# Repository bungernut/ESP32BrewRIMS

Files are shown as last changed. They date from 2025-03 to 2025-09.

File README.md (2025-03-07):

# ESP32BrewREMS

# Documentation
I dont know why, but it's been a real pain to find documentation for the ESP32 device. I'm using a HiLetgo ESP32 OLED WiFi Kit V3. This is apparently really a product by Heltec: https://heltec.org/project/wifi-kit32-v3/

USB-Serial Driver: https://www.silabs.com/developer-tools/usb-to-uart-bridge-vcp-drivers

This library seems to be really important https://github.com/HelTecAutomation/Heltec_ESP32

None of their links work, so I'm going to try to scrape together what I can find:  
## Specifications
* Master Chip  ESP32-S3FN8(Xtensa®32-bit lx7 dual core processor)  
* USB to Serial Chip  CP2102  
* WiFi  802.11 b/g/n, up to 150Mbps  
* Bluetooth LE  Bluetooth 5, Bluetooth mesh  
* Hardware Resource  7*ADC1+2*ADC2; 7*Touch; 3*UART; 2*I2C; 2*SPI, etc.  
* Memory  384KB ROM;  512KB SRAM;  16KB RTC SRAM;  8MB SiP Flash  
* 2*1.25 lithium battery interface;  2*18*2.54 Header Pin  
* Battery  3.7V lithium battery power supply and charging  



### Encoder Input
I should have looked at the spec sheet. I think the circuit is close w/ the input pullup:
https://www.digikey.com/en/products/detail/bourns-inc/PEC11H-4220F-S0024/12349532


ledc is a little weird but we're trying to use if for power control (https://docs.espressif.com/projects/arduino-esp32/en/latest/api/ledc.html).
The range of settings is limited between freq and resolution.
Run this script to get the output https://github.com/espressif/arduino-esp32/blob/master/libraries/ESP32/examples/AnalogOut/ledcFrequency/ledcFrequency.ino
```
Bit resolution | Min Frequency [Hz] | Max Frequency [Hz]
             1 |              19532 |           20039138
             2 |               9766 |           10019569
             3 |               4883 |            5009784
             4 |               2442 |            2504892
             5 |               1221 |            1252446
             6 |                611 |             626223
             7 |                306 |             313111
             8 |                153 |             156555
             9 |                 77 |              78277
            10 |                 39 |              39138
            11 |                 20 |              19569
            12 |                 10 |               9784
            13 |                  5 |               4892
            14 |                  3 |               2446
```

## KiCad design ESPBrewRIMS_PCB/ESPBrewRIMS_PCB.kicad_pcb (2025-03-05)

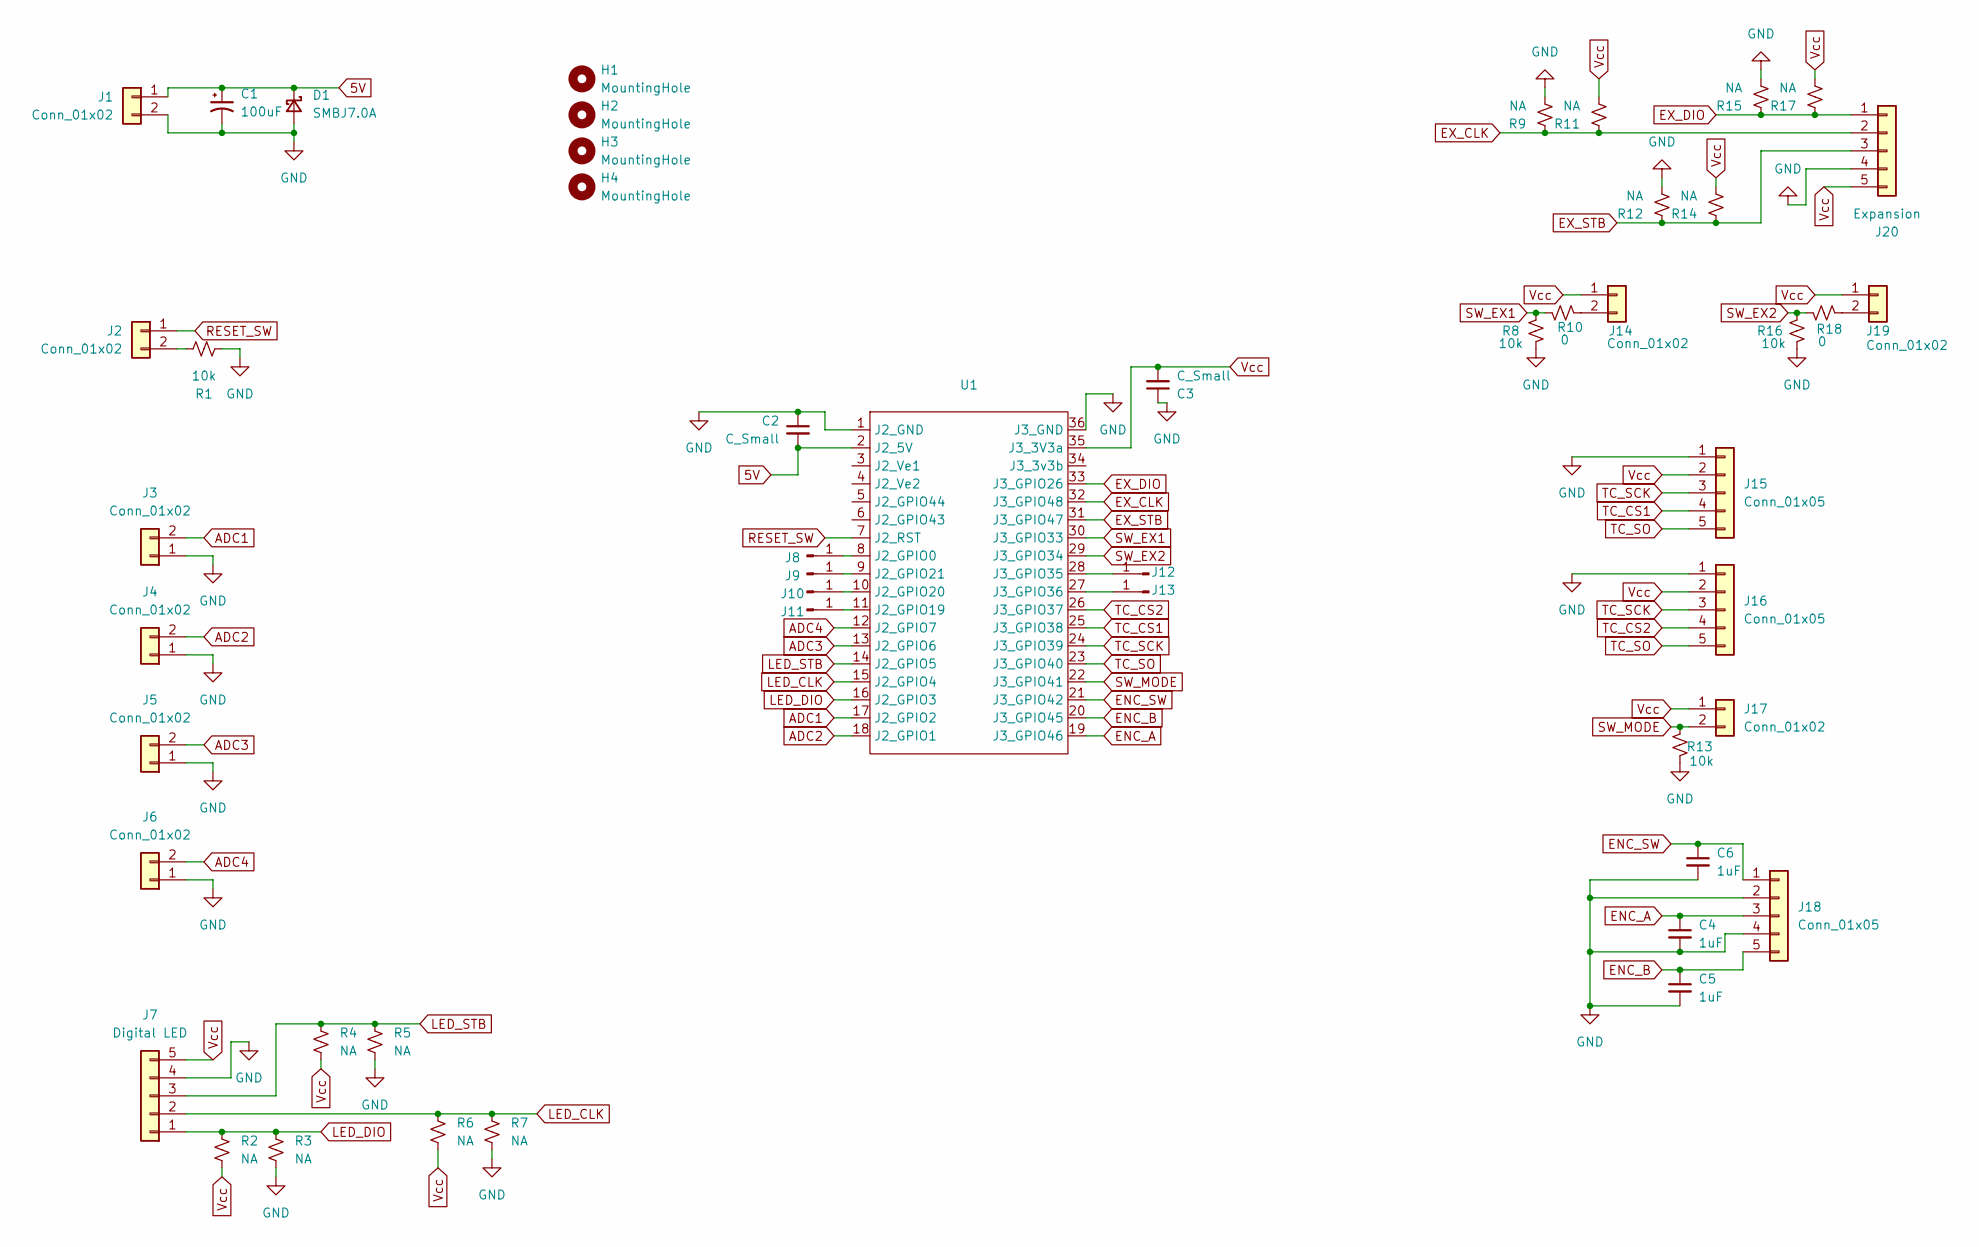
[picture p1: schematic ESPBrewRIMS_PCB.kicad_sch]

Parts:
C1: 100uF; CP_Radial_D8.0mm_P3.50mm
C2, C3: C_Small; C_0805_2012Metric_Pad1.18x1.45mm_HandSolder
C4, C5, C6: 1uF; C_0805_2012Metric_Pad1.18x1.45mm_HandSolder
D1: SMBJ7.0A; D_SMA-SMB_Universal_Handsoldering
H1, H2, H3, H4: MountingHole; MountingHole_3mm
J1, J2, J3, J4, J5, J6, J14, J17, J19: Conn_01x02; Molex_SL_171971-0002_1x02_P2.54mm_Vertical
J7: Digital LED; Molex_SL_171971-0005_1x05_P2.54mm_Vertical
J8, J9, J10, J11, J12, J13: Conn_01x01_Pin; PinSocket_1x01_P2.54mm_Vertical
J15, J16, J18: Conn_01x05; Molex_SL_171971-0005_1x05_P2.54mm_Vertical
J20: Expansion; PinHeader_1x05_P2.54mm_Vertical
R1, R8, R13, R16: 10k; R_0805_2012Metric_Pad1.20x1.40mm_HandSolder
R2, R3, R4, R5, R6, R7, R9, R11, R12, R14, R15, R17: NA; R_0805_2012Metric_Pad1.20x1.40mm_HandSolder
R10, R18: 0; R_0805_2012Metric_Pad1.20x1.40mm_HandSolder
U1: DIP-36_907_ELL

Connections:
5V: C1.1, C2.2, D1.1 (K), J1.1, U1.2 (J2_5V)
ADC1: J3.2, U1.17 (J2_GPIO2)
ADC2: J4.2, U1.18 (J2_GPIO1)
ADC3: J5.2, U1.13 (J2_GPIO6)
ADC4: J6.2, U1.12 (J2_GPIO7)
ENC_A: C4.1, J18.3, U1.19 (J3_GPIO46)
ENC_B: C5.1, J18.5, U1.20 (J3_GPIO45)
ENC_SW: C6.1, J18.1, U1.21 (J3_GPIO42)
EX_CLK: J20.2, R9.1, R11.1, U1.32 (J3_GPIO48)
EX_DIO: J20.1, R15.1, R17.1, U1.33 (J3_GPIO26)
EX_STB: J20.3, R12.1, R14.1, U1.31 (J3_GPIO47)
GND: C1.2, C2.1, C3.1, C4.2, C5.2, C6.2, D1.2 (A), J1.2, J3.1, J4.1, J5.1, J6.1, J7.4, J15.1, J16.1, J18.2, J18.4, J20.4, R1.2, R3.2, R5.2, R7.2, R8.2, R9.2, R12.2, R13.2, R15.2, R16.2, U1.1 (J2_GND), U1.36 (J3_GND)
LED_CLK: J7.2, R6.1, R7.1, U1.15 (J2_GPIO4)
LED_DIO: J7.1, R2.1, R3.1, U1.16 (J2_GPIO3)
LED_STB: J7.3, R4.1, R5.1, U1.14 (J2_GPIO5)
unnamed: J2.2, R1.1
unnamed: J8.1, U1.8 (J2_GPIO0)
unnamed: J9.1, U1.9 (J2_GPIO21)
unnamed: J10.1, U1.10 (J2_GPIO20)
unnamed: J11.1, U1.11 (J2_GPIO19)
unnamed: J12.1, U1.28 (J3_GPIO35)
unnamed: J13.1, U1.27 (J3_GPIO36)
unnamed: J14.2, R10.2
unnamed: J19.2, R18.2
RESET_SW: J2.1, U1.7 (J2_RST)
SW_EX1: R8.1, R10.1, U1.30 (J3_GPIO33)
SW_EX2: R16.1, R18.1, U1.29 (J3_GPIO34)
SW_MODE: J17.2, R13.1, U1.22 (J3_GPIO41)
TC_CS1: J15.4, U1.25 (J3_GPIO38)
TC_CS2: J16.4, U1.26 (J3_GPIO37)
TC_SCK: J15.3, J16.3, U1.24 (J3_GPIO39)
TC_SO: J15.5, J16.5, U1.23 (J3_GPIO40)
Vcc: C3.2, J7.5, J14.1, J15.2, J16.2, J17.1, J19.1, J20.5, R2.2, R4.2, R6.2, R11.2, R14.2, R17.2, U1.35 (J3_3V3a)

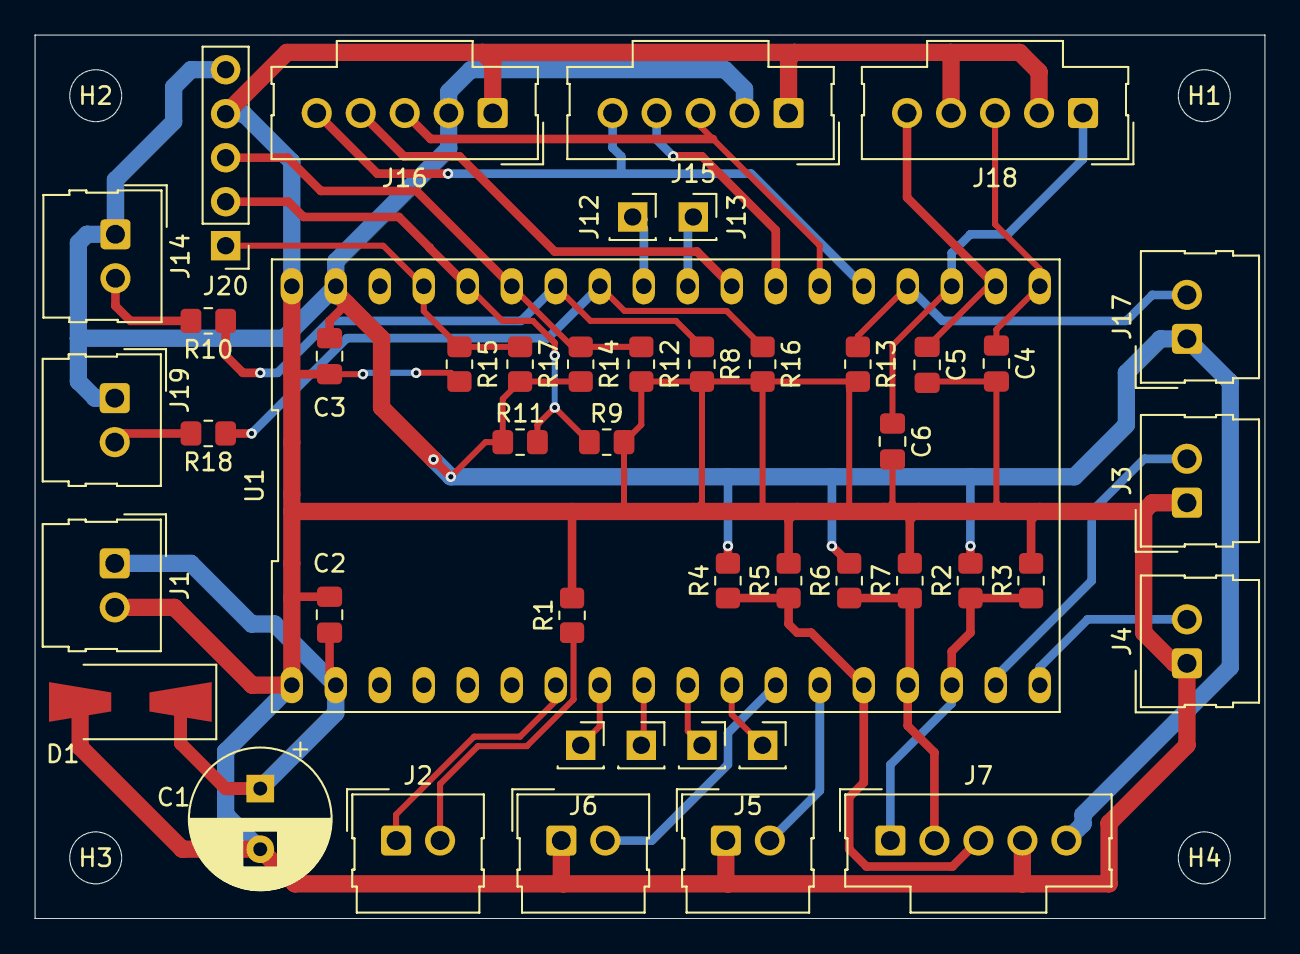
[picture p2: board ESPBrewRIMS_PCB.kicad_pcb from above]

Board: 2 copper layers, 71.0 x 51.0 mm, 50 parts (0 on the bottom side), 33 nets.

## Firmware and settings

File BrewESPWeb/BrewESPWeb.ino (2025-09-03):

#include "SECRETS.h"
#include <WiFi.h>
#include <WebServer.h>
#include <Wire.h>
#include <SPI.h>
#include "HT_SSD1306Wire.h"  // legacy include: `#include "SSD1306.h"`
#include "max6675.h"         // Adafruit Thermocouple
#include <AutoPID.h>         // https://ryand.io/AutoPID/#autopidautopid-constructor

/*
Heltec WiFi Kit 32(V3)

*/

const char* ssid = MY_SSID;
const char* password = MY_PASSKEY;

#define PINLED 35   // Onboard White LED
#define PINSSR 6    // Use this one for heater relay control
#define PIN_POW A1  // The ADC for the POWer

#define PIN_SCK 39    //TC1/2
#define PIN_SDO 40    //TC1/2
#define PIN_TC1CS 38  //TC1
#define PIN_TC2CS 37  //TC2

// Setup Hardware
WebServer server(80);
String header;
//WiFiClient wifi_client;
static SSD1306Wire display(0x3c, 500000, SDA_OLED, SCL_OLED, GEOMETRY_128_64, RST_OLED);  // addr , freq , i2c group , resolution , rst
MAX6675 thermocouple1(PIN_SCK, PIN_TC1CS, PIN_SDO);
MAX6675 thermocouple2(PIN_SCK, PIN_TC2CS, PIN_SDO);

// These are parameter that are set by users with whatever UI
double mashsettemp = 150;      // Set point for mash temperature in F
double maxrimstemp = 160;      // Max temp at output of the RIMS heater
bool enable_ops = false;  // A switch that disables the heater and stuff

double mashtemp = 0;
double rimstemp = 0;
double power_tot = 0;
double pid_out = 0;
const double KP = 10.;
const double KI = 0.1;  //.0003
const double KD = 0.1;  //.01;
const int OUTPUT_MIN = 0;
const int OUTPUT_MAX = 3276;  //maxheaterset / heaterspec * 4095.
AutoPID myPID(&rimstemp, &mashsettemp, &pid_out, OUTPUT_MIN, OUTPUT_MAX, KP, KI, KD);


// Function to handle the root URL and show the current states
void handleRoot() {
  String html = "<!DOCTYPE html><html><head><meta name=\"viewport\" content=\"width=device-width, initial-scale=1\">";
  html += "<link rel=\"icon\" href=\"data:,\">";
  html += "<style>html { font-family: Helvetica; display: inline-block; margin: 0px auto; text-align: center; font-size: 20px}";
  html += ".button { background-color: #4CAF50; border: none; color: white; padding: 12px 20px; \
                     border-radius: 8px; text-decoration: none; font-size: 20px; margin: 2px; cursor: pointer;}";
  html += ".button2 { background-color: #555555; }</style></head>";
  html += "<body><h1>ESPBrew</h1>";
  html += "<p>";
  if (enable_ops == false) {
    html += "<span style=\"color:red;\">DISABLED</span>&nbsp;";
    html += "<a href=\"/enable\"><button class=\"button\">ENABLE</button></a>";
  } else {
    html += "<span style=\"color:green;\">ENABLED</span>&nbsp;";
    html += "<a href=\"/disable\"><button class=\"button\", style=\"background-color:red\">DISABLE</button></a>";
  }
  html += "</p>";
  html += "<br>";
  // html += "<h2>MASH Temp</h2>";
  // html += "<a href=\"/mash_m5\"><button class=\"button\" style=\"background-color:blue;\">-5</button></a>&nbsp;";
  // html += "<a href=\"/mash_m1\"><button class=\"button\" style=\"background-color:blue;\">-1</button></a>&nbsp;";
  // html += String(mashsettemp)+"&nbsp;";
  // html += "<a href=\"/mash_p1\"><button class=\"button\" style=\"background-color:red;\">+1</button></a>&nbsp;";
  // html += "<a href=\"/mash_p5\"><button class=\"button\" style=\"background-color:red;\">+5</button></a>&nbsp;";
  // html += "<br>";
  html += "<h2>RIMS Temp</h2>";
  html += "<p style=\"font_size:10;text-align:center\">Set Max temp allowed before shutting off heater</p>";
  html += "<a href=\"/rims_m5\"><button class=\"button\" style=\"background-color:blue;\">-5</button></a>&nbsp;";
  html += "<a href=\"/rims_m1\"><button class=\"button\" style=\"background-color:blue;\">-1</button></a>&nbsp;";
  html += String(maxrimstemp)+"&nbsp;";
  html += "<a href=\"/rims_p1\"><button class=\"button\" style=\"background-color:red;\">+1</button></a>&nbsp;";
  html += "<a href=\"/rims_p5\"><button class=\"button\" style=\"background-color:red;\">+5</button></a>&nbsp;";
  html += "<br>";
  html += "<p style=\"font_size:16;color:grey\">RIMS="+String(rimstemp)+"</p>";
  html += "<p style=\"font_size:16;color:grey\">MASH="+String(mashtemp)+"</p>";
  html += "</body></html>";
  server.send(200, "text/html", html);
}
void handleEnable() {
  enable_ops = true;
  server.sendHeader("Location", "/",true);
  server.send(302, "text/plain", "");
}
void handleDisable() {
  enable_ops = false;
  server.sendHeader("Location", "/",true);
  server.send(302, "text/plain", "");
}
void handleMashP5() {
  mashsettemp = mashsettemp+5.0;
  server.sendHeader("Location", "/",true);
  server.send(302, "text/plain", "");
}
void handleMashP1() {
  mashsettemp = mashsettemp+1.0;
  server.sendHeader("Location", "/",true);
  server.send(302, "text/plain", "");
}
void handleMashM5() {
  mashsettemp = mashsettemp-5.0;
  server.sendHeader("Location", "/",true);
  server.send(302, "text/plain", "");
}
void handleMashM1() {
  mashsettemp = mashsettemp-1.0;
  server.sendHeader("Location", "/",true);
  server.send(302, "text/plain", "");
}
// RIMS Temps
void handleRIMSP5() {
  maxrimstemp = maxrimstemp+5.0;
  server.sendHeader("Location", "/",true);
  server.send(302, "text/plain", "");
}
void handleRIMSP1() {
  maxrimstemp = maxrimstemp+1.0;
  server.sendHeader("Location", "/",true);
  server.send(302, "text/plain", "");
}
void handleRIMSM5() {
  maxrimstemp = maxrimstemp-5.0;
  server.sendHeader("Location", "/",true);
  server.send(302, "text/plain", "");
}
void handleRIMSM1() {
  maxrimstemp = maxrimstemp-1.0;
  //handleRoot();
  server.sendHeader("Location", "/",true);
  server.send(302, "text/plain", "");
}

// Loop Parameters
unsigned long loop_time_curr;
unsigned long loop_time_prev;
const unsigned long update_time = 1000;
int wifi_status = 0;

void WiFiStationConnected(WiFiEvent_t event, WiFiEventInfo_t info) {
  Serial.println("Connected to AP successfully!");
  wifi_status = 1;
}

void WiFiGotIP(WiFiEvent_t event, WiFiEventInfo_t info) {
  Serial.println("WiFi connected");
  Serial.println("IP address: ");
  Serial.println(WiFi.localIP());
  Serial.println(WiFi.localIP()[3]);
  wifi_status = int(WiFi.localIP()[3]);
}

void WiFiStationDisconnected(WiFiEvent_t event, WiFiEventInfo_t info) {
  Serial.println("Disconnected from WiFi access point");
  Serial.print("WiFi lost connection. Reason: ");
  Serial.println(info.wifi_sta_disconnected.reason);
  Serial.println("Trying to Reconnect");
  WiFi.begin(ssid, password);
  wifi_status = 0;
}

void setup() {
  Serial.begin(115200);
  VextON();
  delay(100);
  pinMode(PINLED, OUTPUT);
  digitalWrite(PINLED, true);
  delay(1000);
  digitalWrite(PINLED, false);
  delay(1000);
  pinMode(PINSSR, OUTPUT);
  digitalWrite(PINLED, false);
  bool ledstat = ledcAttach(PINLED, 30, 12);  // PIN, freq (Hz), PWM Resolution (8bit=0-255) 12=4096
  bool ssrstat = ledcAttach(PINSSR, 30, 12);  // PIN, freq (Hz), PWM Resolution (8bit=0-255) 12=4096
  Serial.println("led stat:" + String(ledstat));
  Serial.println("led stat:" + String(ssrstat));
  display.init();
  display.setFont(ArialMT_Plain_16);
  display.clear();
  display.setTextAlignment(TEXT_ALIGN_LEFT);
  display.drawString(5, 5, "Setup...");
  display.display();

  // delete old config
  WiFi.disconnect(true);
  delay(1000);
  WiFi.onEvent(WiFiStationConnected, WiFiEvent_t::ARDUINO_EVENT_WIFI_STA_CONNECTED);
  WiFi.onEvent(WiFiGotIP, WiFiEvent_t::ARDUINO_EVENT_WIFI_STA_GOT_IP);
  WiFi.onEvent(WiFiStationDisconnected, WiFiEvent_t::ARDUINO_EVENT_WIFI_STA_DISCONNECTED);


  server.on("/", handleRoot);
  server.on("/enable", handleEnable);
  server.on("/disable", handleDisable);
  server.on("/mash_p5", handleMashP5);
  server.on("/mash_p1", handleMashP1);
  server.on("/mash_m1", handleMashM1);
  server.on("/mash_m5", handleMashM5);
  server.on("/rims_p5", handleRIMSP5);
  server.on("/rims_p1", handleRIMSP1);
  server.on("/rims_m5", handleRIMSM5);
  server.on("/rims_m1", handleRIMSM1);

  WiFi.begin(ssid, password);
  delay(1000);
  read_temps();
  server.begin();
  Serial.println("HTTP server started");
  Serial.println("Setup Done");
}

void loop() {
  loop_time_curr = millis();
  if (loop_time_curr - loop_time_prev > update_time) {
    read_temps();
    update_power();
    update_display();
    loop_time_prev = loop_time_curr;
  }
  // Handle incoming client requests
  server.handleClient();
}

void update_display(void) {
  display.clear();
  display.setFont(ArialMT_Plain_16);
  // WiFi Status
  IPAddress ip = WiFi.localIP();
  display.setTextAlignment(TEXT_ALIGN_RIGHT);
  display.drawString(128, 0, "WiFi:" + String(ip[0]) + "." + String(ip[1]) + "." + String(ip[2]) + "." + String(ip[3]));
  display.setTextAlignment(TEXT_ALIGN_LEFT);
  display.setFont(ArialMT_Plain_16);
  //display.drawString(0,0,  String(int(power_tot)) + " / " + String(int(pid_out*100/4096)));
  //display.drawString(0, 15, "Mash " + String(int(mashtemp)) + "/" + String(int(mashsettemp)));
  display.drawString(0, 20, "RIMS " + String(int(rimstemp)) + "/" + String(int(maxrimstemp)));
  if (enable_ops == true) {
    display.drawString(10, 45, "ENABLED");
  } else {
    display.drawString(10, 45, "DISABLED");
  }
  display.display();
}

void update_power() {
  if (rimstemp > maxrimstemp or enable_ops == false) {
    ledcWrite(PINLED, 0);
    ledcWrite(PINSSR, 0);
  } else {
    myPID.run();
    ledcWrite(PINLED, int(pid_out));
    ledcWrite(PINSSR, int(pid_out));
  }
}

void read_temps() {
  mashtemp = thermocouple1.readFahrenheit();
  rimstemp = thermocouple2.readFahrenheit();
}

void VextON(void) {
  // I dont know what these do, they were in minimal example
  pinMode(Vext, OUTPUT);
  digitalWrite(Vext, LOW);
}

void VextOFF(void) {
  // I dont know what these do, they were in minimal example
  pinMode(Vext, OUTPUT);
  digitalWrite(Vext, HIGH);
}

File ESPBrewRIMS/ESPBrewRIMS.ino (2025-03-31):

#include <Wire.h>
#include "HT_SSD1306Wire.h"  // legacy include: `#include "SSD1306.h"`
#include "AiEsp32RotaryEncoder.h"
#include "max6675.h"     // Adafruit Thermocouple
#include <TM1638lite.h>  // 7Seg/8digit LED, LEDs, Buttons
#include <AutoPID.h>     // https://ryand.io/AutoPID/#autopidautopid-constructor

#define PIN_ENABLE 41
#define PINLED 35      // Onboard White LED
#define PINSSR 6      // Use this one for heater relay control
#define PIN_TOTPOW A0  // The ADC for the TOTal POWer
#define PIN_HTRPOW A1  // ADC for the HeaTeR POWer

#define PIN_SCK 39    //TC
#define PIN_SDO 40    //TC
#define PIN_TC1CS 38  //TC
#define PIN_TC2CS 37  //TC2

#define PIN_LEDDIO GPIO3  // DIO
#define PIN_LEDCLK GPIO4  // CLK
#define PIN_LEDSTB GPIO5  // STB (strobe)


// Setup Constants
const float POWHEATER = 1650.;        // Watts; the power of the heater
const float POWERLIMIT = 12. * 120.;  // Watts - Limit power to 12A

/*
EPP32 HiLego Device (Amazon https://www.amazon.com/dp/B07DKD79Y9?ref=ppx_yo2ov_dt_b_fed_asin_title)
Inputs:
2 PT100 sensors, 1 for mash-tun and 1 for RIMS system
1 Power sensor on the AC to limit heater power (Amazon https://www.amazon.com/dp/B0C33L14LY?ref=ppx_yo2ov_dt_b_fed_asin_title&th=1)
  This will produce 1V at 20A so resolution at 10 bit is 20mA
Encoder or push button to change temp or power settings?

Have a 4 pos switch that will select different modes for the RIMS system
https://www.amazon.com/dp/B09P9T86TT?ref=ppx_yo2ov_dt_b_fed_asin_title
0) OFF
1) Heating water, for mash in does not regulate MAXTEMP of RIMS system
2) Mashing - Dont want to denature enzymes so need to regulate the max temp in REMS as well
3) ??
**^^** Thinking about not doing this, how about just an enable switch.

PID? https://github.com/r-downing/AutoPID
May consider PID control, but for now lets look at simpler methods.
*/

// Setup Hardware
static SSD1306Wire display(0x3c, 500000, SDA_OLED, SCL_OLED, GEOMETRY_128_64, RST_OLED);  // addr , freq , i2c group , resolution , rst
MAX6675 thermocouple1(PIN_SCK, PIN_TC1CS, PIN_SDO);
MAX6675 thermocouple2(PIN_SCK, PIN_TC2CS, PIN_SDO);
TM1638lite ledDisplay(PIN_LEDSTB, PIN_LEDCLK, PIN_LEDDIO);  //STB,CLK,DIO

bool enable_ops = 0;  // A switch that disables the heater and stuff

// These are parameter that are set by users with whatever UI
double mashsettemp = 150;      // Set point for mash temperature in F
double maxrimstemp = 160;      // Max temp at output of the RIMS heater
double maxpowerpercent = 100;  // it will be actually lower than 100% of maxpower of heater
// Values used to deregulate the power a little so it's not pulling 15A
const double maxheaterset = 1300;  //Watts
const double heaterspec = 1650;    //watts


double mashtemp = 0;
double rimstemp = 0;
double power_tot = 0;
double pid_out = 0;
#define KP 3.14
#define KI .0003
#define KD 0
#define OUTPUT_MIN 0
#define OUTPUT_MAX maxheaterset / heaterspec * 4095.
AutoPID myPID(&mashtemp, &mashsettemp, &pid_out, OUTPUT_MIN, OUTPUT_MAX, KP, KI, KD);

// For displaying on digital LED
String temp_str;
char temp_cstr_array[3];

unsigned long loop_time_curr;
unsigned long loop_time_prev;
const unsigned long update_time = 500;
const unsigned long selection_timeout = 5000;  // How many seconds before encoder times out
unsigned long select_time_last = 0;
int selected_parmeter = 0;  // [ POWER, MASH_TEMP, RIMS_TEMP ]
bool selection_active = 0;



void setup() {
  Serial.begin(115200);
  VextON();
  delay(100);
  display.init();
  display.setFont(ArialMT_Plain_10);
  // Setup Enable Switch
  pinMode(PIN_ENABLE, INPUT);
  pinMode(PINLED, OUTPUT);
  digitalWrite(PINLED, true);
  delay(1000);
  digitalWrite(PINLED, false);
  delay(1000);
  pinMode(PINSSR, OUTPUT);
  digitalWrite(PINLED, false);
  bool ledstat = ledcAttach(PINLED, 30, 12);  // PIN, freq (Hz), PWM Resolution (8bit=0-255) 12=4096
  bool ssrstat = ledcAttach(PINSSR, 30, 12);  // PIN, freq (Hz), PWM Resolution (8bit=0-255) 12=4096
  Serial.println("led stat:" + String(ledstat));
  Serial.println("led stat:" + String(ssrstat));

  ledDisplay.reset();
  ledDisplay.displayText("SETUP");

  read_temps();
  //update_display();
  Serial.println("Setup Done");
}



void loop() {
  loop_time_curr = millis();
  if (loop_time_curr - loop_time_prev >= update_time) {
    loop_time_prev = loop_time_curr;
    enable_ops = true;  // digitalRead(PIN_ENABLE);
    //Serial.println(String(enable_ops) + " " + String(loop_time_curr));
    if (enable_ops) {
      read_powers();
      read_temps();
      update_power();
    }
    update_display();
  }
  // myPID.reset();
}

void update_power() {
  // if (mashtemp > mashsettemp) {
  //   ledcWrite(PINLED,0);
  // }
  // else if (rimstemp > maxrimstemp) {
  //   ledcWrite(PINLED,0);
  // }
  // else {
  //   ledcWrite(PINLED,1000);
  // }
  myPID.run();
  if (enable_ops == true){
    ledcWrite(PINLED, int(pid_out));
    ledcWrite(PINSSR, int(pid_out));
    //Serial.println(double(pid_out));
  }
  else {
    ledcWrite(PINLED, 0);
    ledcWrite(PINSSR, 0);
  }
}
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

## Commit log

2025-03-01 A UI working now w/ encoder and enable switch
2025-03-04 ignore kicad backups
2025-03-04 add kicad files wip
    [ESPBrewRIMS_PCB.kicad_pcb, ESPBrewRIMS_PCB.kicad_sch]
2025-03-04 Partially assigned footprints
2025-03-05 Sent version to JLCPCB for print
    [ESPBrewRIMS_PCB-B_Cu.gbr, ESPBrewRIMS_PCB-B_Mask.gbr, ESPBrewRIMS_PCB-B_Paste.gbr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]
2025-03-05 updated encoder cap values
    [ESPBrewRIMS_PCB.kicad_sch]
2025-03-07 added PID to control LED
2025-03-17 removed encoder, struggling w/ LEDs
2025-03-17 added AC sch
    [ESPBrewRIMS_PCB.kicad_sch]
2025-09-03 brewed with this version, removed useless sensor
